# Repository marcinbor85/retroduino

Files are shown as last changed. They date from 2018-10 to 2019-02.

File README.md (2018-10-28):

# retroduino
Open hardware 8051-based arduino-compatible microcomputer

## Features
- Arduino-mega compatible pinout
- AT89S8253 based
- 32kB RAM for data memory
- 32kB RAM for program code
- 32kB EEPROM for non-volatile program code
- build-in bootloader (booting from ROM, copy EEPROM to RAM and run)
- USB PC connection (fast program code loading directly to RAM or to EEPROM)
- external data bus for external peripherals

## PCB
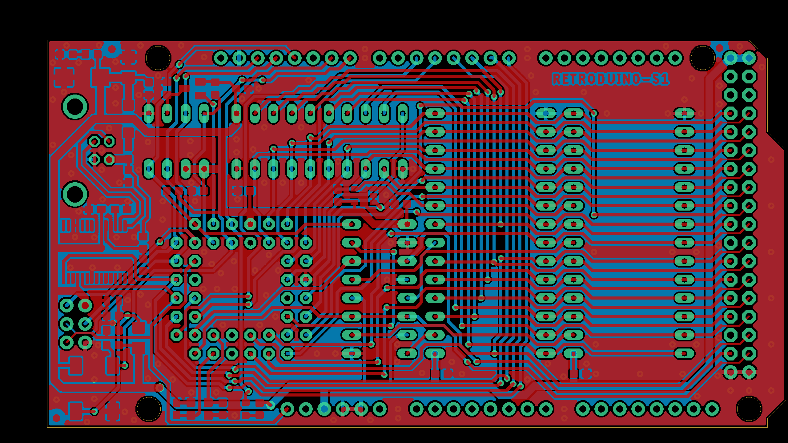
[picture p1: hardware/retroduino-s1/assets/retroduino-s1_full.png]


## Electric diagram
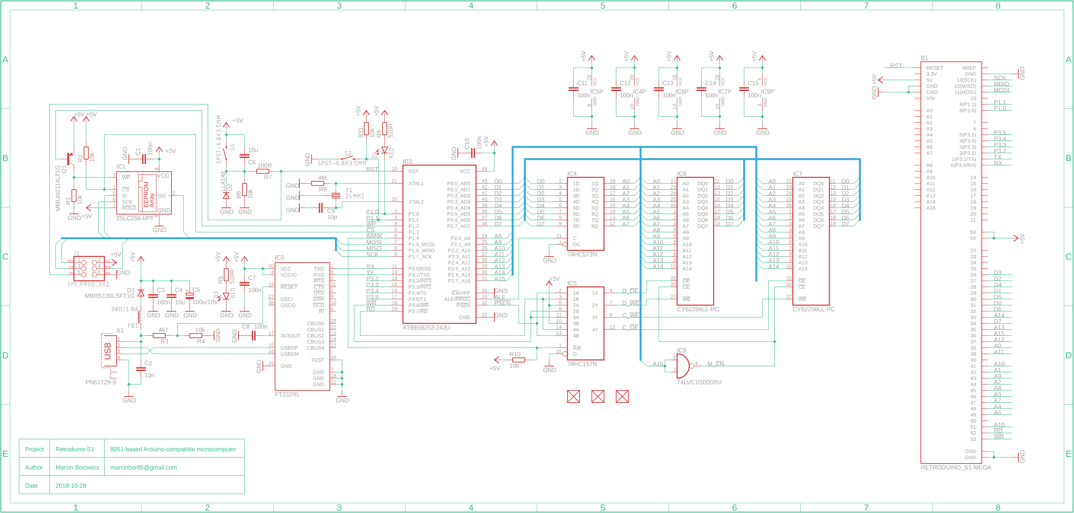
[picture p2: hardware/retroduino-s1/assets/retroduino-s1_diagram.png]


## Project purpose
- "because you can"

## Programming
- recommended SDCC compiler

## Memory layout

### Program bus
- 0x0000-0x2FFF - internal flash with bootloader
- 0x8000-0xFFFF - external program code memory
### Data bus
- 0x0000-0x00FF - internal ram
- 0x0100-0x7FFF - external peripherals
- 0x8000-0xFFFF - external data memory

## TODO
- [ ] external boards with digital and analog input/outputs
- [ ] PC application to loading code to the retroduino board
- [ ] bootloader with code loading, flashing, coping and app running
- [ ] example firmware applications

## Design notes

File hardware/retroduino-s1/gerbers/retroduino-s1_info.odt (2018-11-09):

PCB: retroduino-s1

Wymiary: 101.6 x 53.3 mm

Laminat: FR4 1.5mm dwuwarstwowy/dwustronny

Miedź: 35um

Wykończenie: HAL + Metalizacja

Soldermaska: Zielona

Bez warstwy opisowej

Ilość otworów: 446

Przelotki: 0.4mm

Ścieżka: 0.25mm

Odstępy: 0.25mm

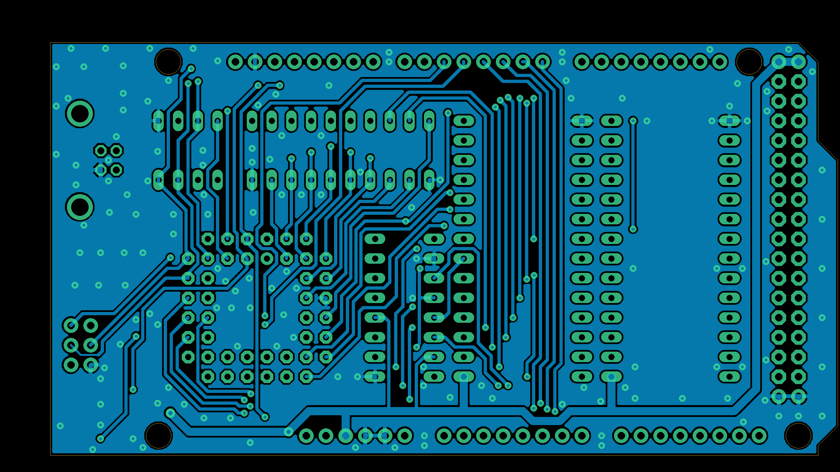
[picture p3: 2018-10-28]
hardware/retroduino-s1/assets/retroduino-s1_bot.png

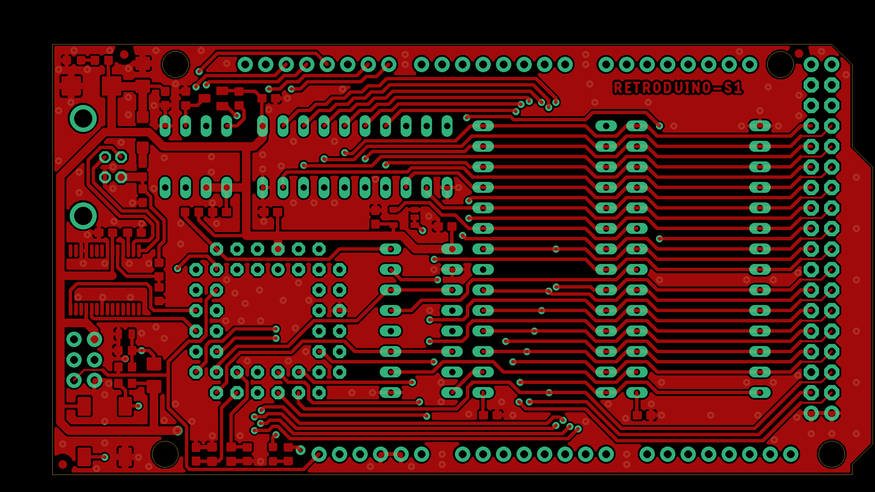
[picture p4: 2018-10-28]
hardware/retroduino-s1/assets/retroduino-s1_top.png

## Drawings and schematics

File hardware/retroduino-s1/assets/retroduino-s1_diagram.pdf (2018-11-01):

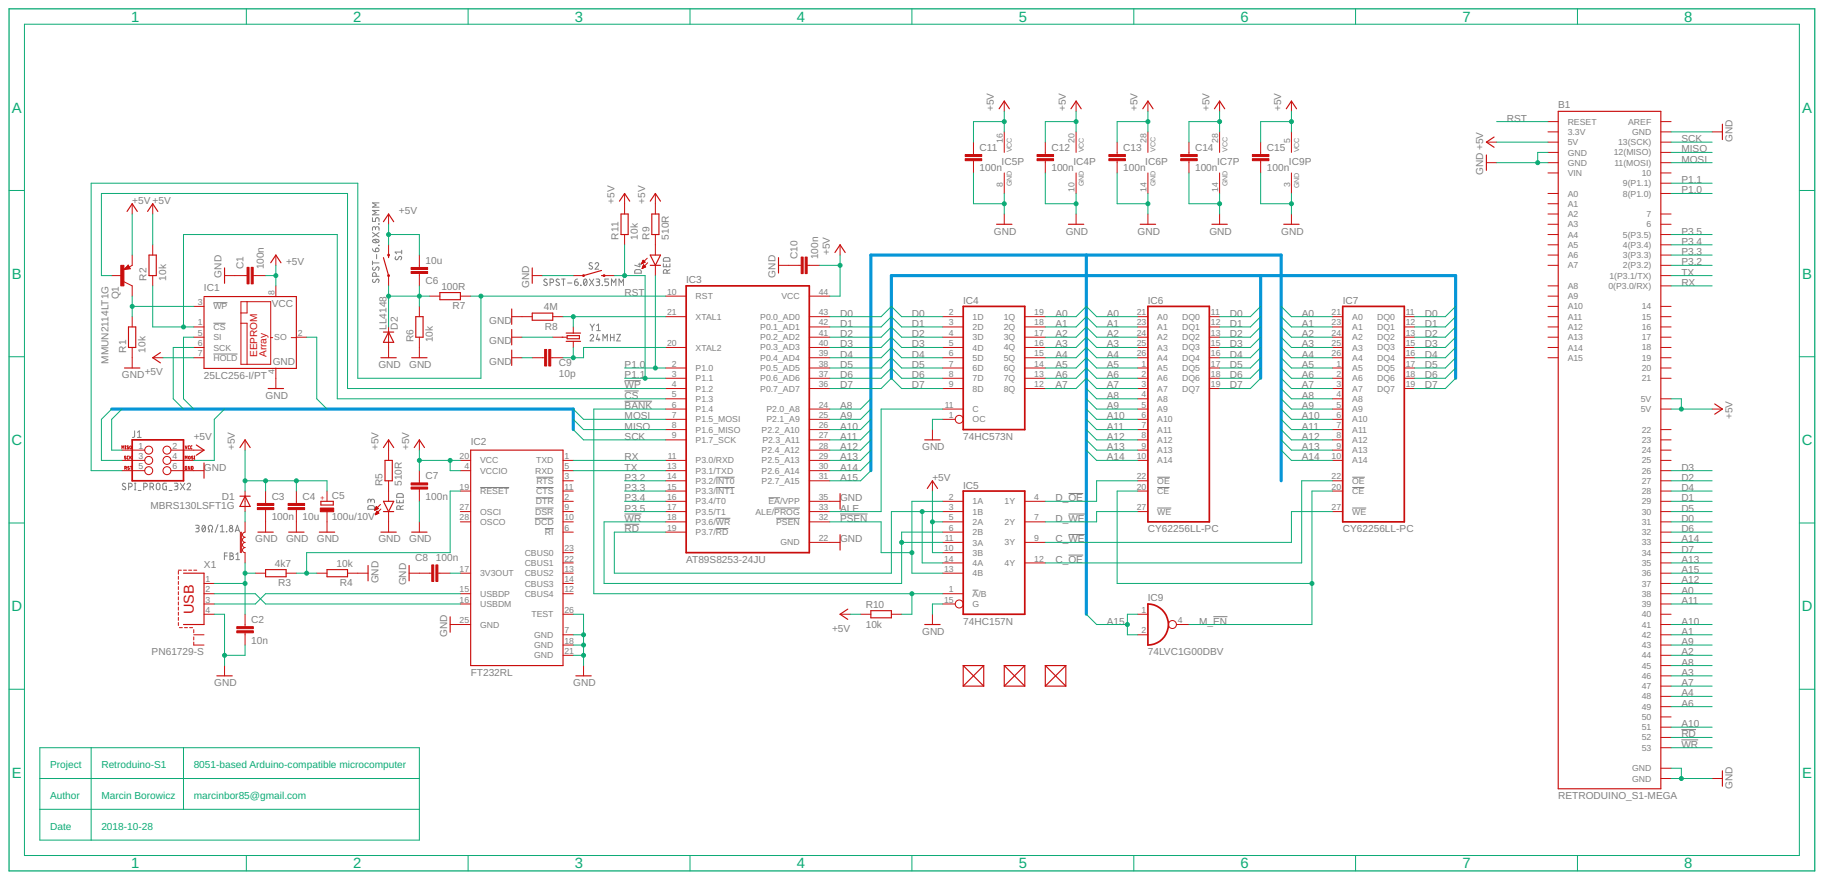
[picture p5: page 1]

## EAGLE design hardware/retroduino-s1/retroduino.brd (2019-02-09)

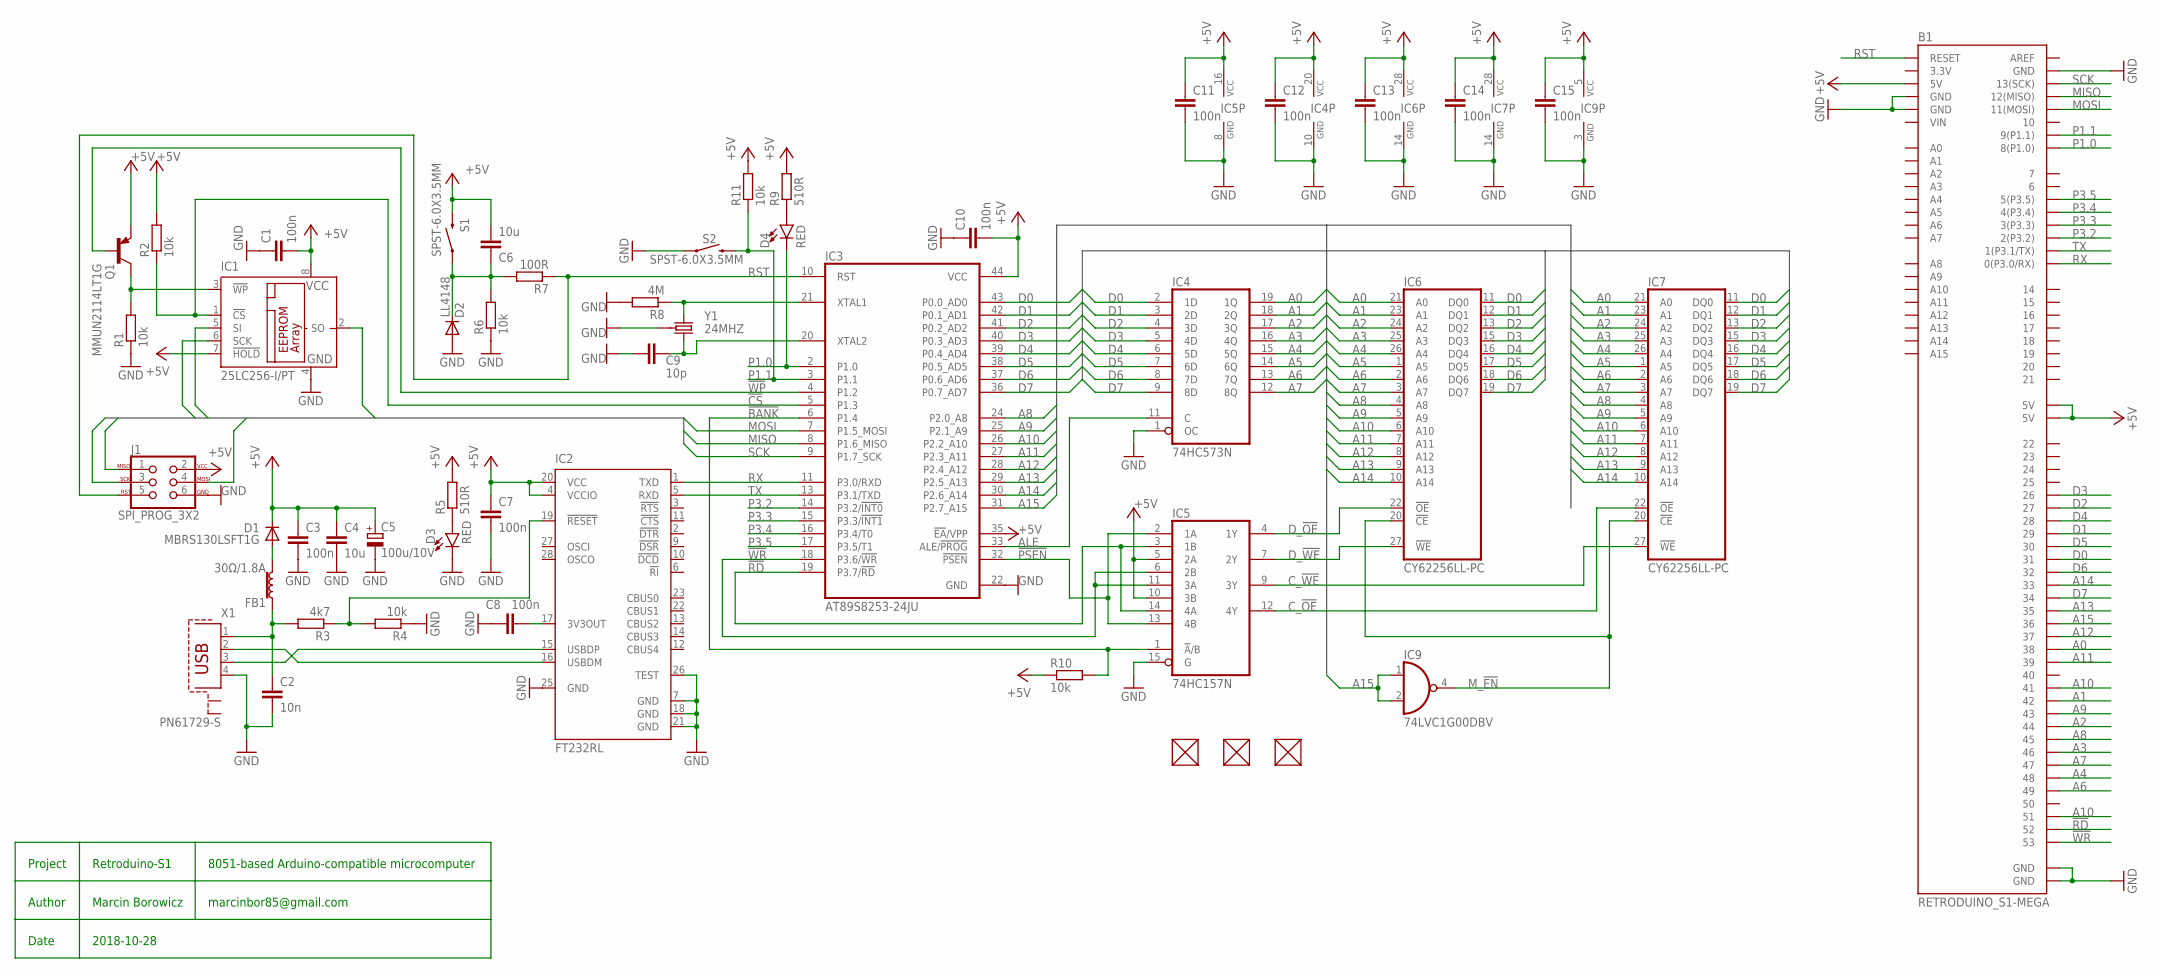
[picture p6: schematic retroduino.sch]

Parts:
B1: RETRODUINO_S1-MEGA; RETRODUINO_S1
C1, C3, C7, C8, C10, C11, C12, C13, C14, C15: 100n; C0603
C2: 10n; C0603
C4, C6: 10u; C1206
C5: 100u/10V; SMC_C
C9: 10p; C0603
D1: MBRS130LSFT1G; SOD123
D2: LL4148; MICROMELF-R
D3, D4: RED; LED-0603
FB1: 30Ω/1.8A; 0603
FUD1, FUD2, FUD3: FIDUCIAL; GHI_FIDUCIAL_40MIL
IC1: 25LC256-I/PT; DIL8
IC2: FT232RL; SSOP28
IC3: AT89S8253-24JU; S44
IC4: 74HC573N; DIL20
IC5: 74HC157N; DIL16
IC6, IC7: CY62256LL-PC; DIL28-6
IC9: 74LVC1G00DBV; SOT23-5
J1: SPI_PROG_3X2; 2X3-NS
Q1: MMUN2114LT1G; SOT23-BEC
R1, R2, R4, R6, R10, R11: 10k; R0603
R3: 4k7; R0603
R5, R9: 510R; R0603
R7: 100R; R0603
R8: 4M; R0603
S1, S2: SPST-6.0X3.5MM; TACTILE_SWITCH_SMD_6.0X3.5MM
X1: PN61729-S
Y1: 24MHZ; CRYSTAL-SMD-3.2X2.5MM

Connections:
!BANK: IC3.6 (P1.4), IC5.1 (!A!/B), R10.2
!CS: IC1.1 (!CS), IC3.5 (P1.3), R2.1
!PSEN: IC3.32 (!PSEN), IC5.2 (1A), IC5.13 (4B)
!RD: B1.52, IC3.19 (P3.7/!RD), IC5.3 (1B), IC5.14 (4A)
!WP: IC3.4 (P1.2), Q1.B
!WR: B1.53, IC3.18 (P3.6/!WR), IC5.6 (2B), IC5.11 (3A)
+5V: B1.5V@0 (5V), B1.5V@1 (5V), B1.5V@2 (5V), C1.2, C3.1, C4.1, C5.+, C6.1, C7.1, C10.2, C11.1, C12.1, C13.1, C14.1, C15.1, D1.C, IC1.7 (!HOLD), IC1.8 (VCC), IC2.4 (VCCIO), IC2.20 (VCC), IC3.35 (!EA!/VPP), IC3.44 (VCC), IC4.20 (VCC), IC5.5 (2A), IC5.10 (3B), IC5.16 (VCC), IC6.28 (VCC), IC7.28 (VCC), IC9.5 (VCC), J1.2, Q1.E, R2.2, R5.2, R9.2, R10.1, R11.2, S1.2
A0: B1.38, IC4.19 (1Q), IC6.21 (A0), IC7.21 (A0)
A1: B1.42, IC4.18 (2Q), IC6.23 (A1), IC7.23 (A1)
A2: B1.44, IC4.17 (3Q), IC6.24 (A2), IC7.24 (A2)
A3: B1.46, IC4.16 (4Q), IC6.25 (A3), IC7.25 (A3)
A4: B1.48, IC4.15 (5Q), IC6.26 (A4), IC7.26 (A4)
A5: IC4.14 (6Q), IC6.1 (A5), IC7.1 (A5)
A6: B1.49, IC4.13 (7Q), IC6.2 (A6), IC7.2 (A6)
A7: B1.47, IC4.12 (8Q), IC6.3 (A7), IC7.3 (A7)
A8: B1.45, IC3.24 (P2.0_A8), IC6.4 (A8), IC7.4 (A8)
A9: B1.43, IC3.25 (P2.1_A9), IC6.5 (A9), IC7.5 (A9)
A10: B1.41, B1.51, IC3.26 (P2.2_A10), IC6.6 (A10), IC7.6 (A10)
A11: B1.39, IC3.27 (P2.3_A11), IC6.7 (A11), IC7.7 (A11)
A12: B1.37, IC3.28 (P2.4_A12), IC6.8 (A12), IC7.8 (A12)
A13: B1.35, IC3.29 (P2.5_A13), IC6.9 (A13), IC7.9 (A13)
A14: B1.33, IC3.30 (P2.6_A14), IC6.10 (A14), IC7.10 (A14)
A15: B1.36, IC3.31 (P2.7_A15), IC9.1 (I0), IC9.2 (I1)
ALE: IC3.33 (ALE/!PROG), IC4.11 (C)
C_!OE: IC5.12 (4Y), IC7.22 (!OE)
C_!WE: IC5.9 (3Y), IC7.27 (!WE)
D0: B1.31, IC3.43 (P0.0_AD0), IC4.2 (1D), IC6.11 (DQ0), IC7.11 (DQ0)
D1: B1.29, IC3.42 (P0.1_AD1), IC4.3 (2D), IC6.12 (DQ1), IC7.12 (DQ1)
D2: B1.27, IC3.41 (P0.2_AD2), IC4.4 (3D), IC6.13 (DQ2), IC7.13 (DQ2)
D3: B1.26, IC3.40 (P0.3_AD3), IC4.5 (4D), IC6.15 (DQ3), IC7.15 (DQ3)
D4: B1.28, IC3.39 (P0.4_AD4), IC4.6 (5D), IC6.16 (DQ4), IC7.16 (DQ4)
D5: B1.30, IC3.38 (P0.5_AD5), IC4.7 (6D), IC6.17 (DQ5), IC7.17 (DQ5)
D6: B1.32, IC3.37 (P0.6_AD6), IC4.8 (7D), IC6.18 (DQ6), IC7.18 (DQ6)
D7: B1.34, IC3.36 (P0.7_AD7), IC4.9 (8D), IC6.19 (DQ7), IC7.19 (DQ7)
D_!OE: IC5.4 (1Y), IC6.22 (!OE)
D_!WE: IC5.7 (2Y), IC6.27 (!WE)
GND: B1.GND@0 (GND), B1.GND@1 (GND), B1.GND@2 (GND), B1.GND@3 (GND), B1.GND@4 (GND), C1.1, C2.2, C3.2, C4.2, C5.-, C7.2, C8.2, C9.1, C10.1, C11.2, C12.2, C13.2, C14.2, C15.2, D2.A, D3.C, IC1.4 (GND), IC2.7 (GND), IC2.18 (GND), IC2.21 (GND), IC2.25 (GND), IC2.26 (TEST), IC3.22 (GND), IC4.1 (OC), IC4.10 (GND), IC5.8 (GND), IC5.15 (G), IC6.14 (GND), IC7.14 (GND), IC9.3 (GND), J1.6, R1.1, R4.1, R6.1, R8.2, S2.1, X1.4, Y1.2 (3), Y1.4 (3)
MISO: B1.12 (12(MISO)), IC1.2 (SO), IC3.8 (P1.6_MISO), J1.1
MOSI: B1.11 (11(MOSI)), IC1.5 (SI), IC3.7 (P1.5_MOSI), J1.4
M_!EN: IC6.20 (!CE), IC7.20 (!CE), IC9.4 (O)
unnamed: C9.2, IC3.20 (XTAL2), Y1.3 (2)
unnamed: IC3.21 (XTAL1), R8.1, Y1.1
unnamed: C6.2, D2.C, R6.2, R7.2, S1.1
unnamed: D3.A, R5.1
unnamed: D4.A, R9.1
unnamed: IC2.16 (USBDM), X1.2
unnamed: C8.1, IC2.17 (3V3OUT)
unnamed: IC2.15 (USBDP), X1.3
unnamed: C2.1, FB1.1, R3.2, X1.1
unnamed: IC1.3 (!WP), Q1.C, R1.2
unnamed: D1.A, FB1.2
unnamed: IC2.19 (!RESET), R3.1, R4.2
P1.0: B1.8 (8(P1.0)), D4.C, IC3.2 (P1.0)
P1.1: B1.9 (9(P1.1)), IC3.3 (P1.1), R11.1, S2.2
P3.2: B1.2 (2(P3.2)), IC3.14 (P3.2/!INT0)
P3.3: B1.3 (3(P3.3)), IC3.15 (P3.3/!INT1)
P3.4: B1.4 (4(P3.4)), IC3.16 (P3.4/T0)
P3.5: B1.5 (5(P3.5)), IC3.17 (P3.5/T1)
RST: B1.RESET, IC3.10 (RST), J1.5, R7.1
RX: B1.0 (0(P3.0/RX)), IC2.1 (TXD), IC3.11 (P3.0/RXD)
SCK: B1.13 (13(SCK)), IC1.6 (SCK), IC3.9 (P1.7_SCK), J1.3
TX: B1.1 (1(P3.1/TX)), IC2.5 (RXD), IC3.13 (P3.1/TXD)

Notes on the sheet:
Author
Project
Date
Marcin Borowicz
Retroduino-S1
2018-10-28
8051-based Arduino-compatible microcomputer
marcinbor85@gmail.com

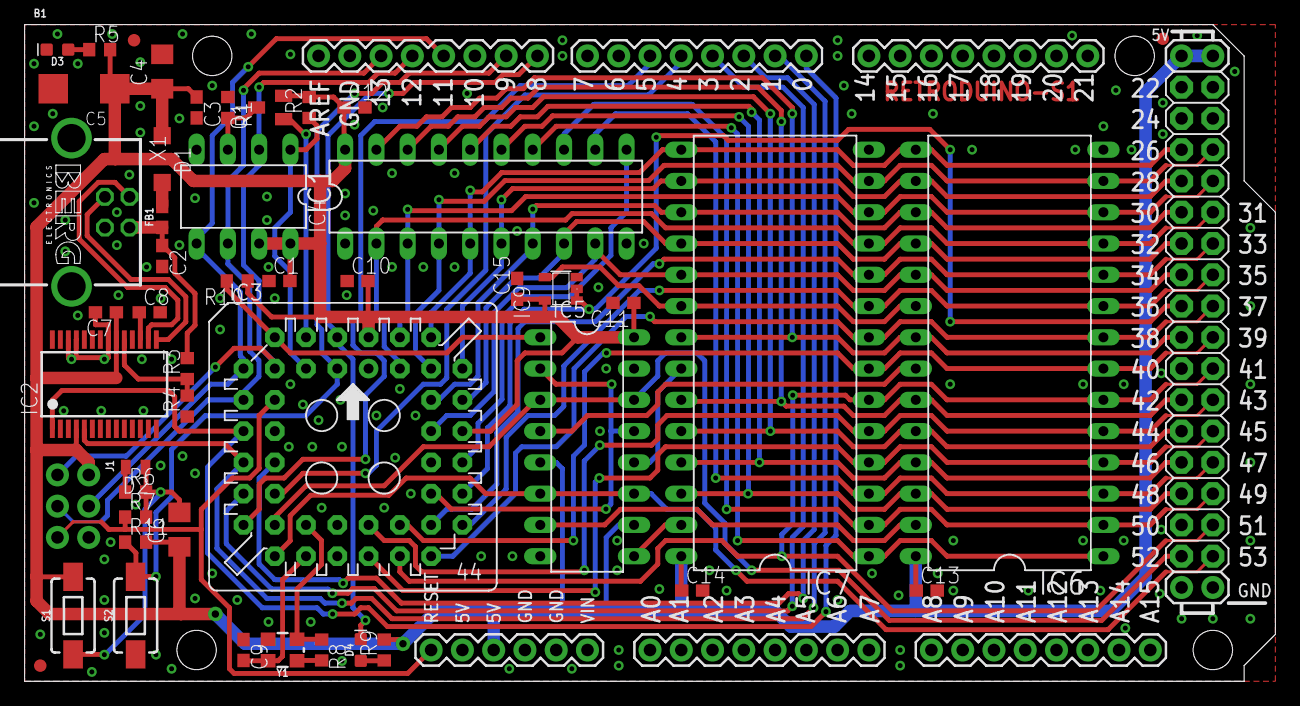
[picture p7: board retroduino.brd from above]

Board: 2 copper layers, 101.6 x 53.3 mm, 49 parts (0 on the bottom side), 62 nets.

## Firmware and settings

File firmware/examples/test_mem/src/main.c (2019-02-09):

#include <at89s8253.h>
#include <stdint.h>

#define LED_PIN_STATE           P1_0
#define BUTTON_PIN_STATE        P1_1
#define BANK_PIN_SELECT         P1_4

#define EXTMEM_ADR_START        ((uint16_t)0x8000)
#define EXTMEM_ADR_END          ((uint16_t)0xFFFF)

static void delay(uint16_t val)
{
        while (val-- > 0) {};
}

static void blinking_loop(void)
{
        uint8_t i = 0;
 
        LED_PIN_STATE = i;
        while (1) {
                delay(50000);
                i = (i == 0) ? 1 : 0;
                LED_PIN_STATE = i;
        }
}

static void signal_error(void)
{
        LED_PIN_STATE = 0;
        while (1) {};
}

static uint8_t calc_pattern(uint16_t adr, uint8_t b)
{
        b ^= adr >> 8;
        b ^= adr;
        return b;
}

static void fill_memory(uint16_t adr_start, uint16_t adr_end, uint8_t pattern)
{
        uint16_t adr;
        uint8_t b;

        adr = adr_start;
        while ((adr >= adr_start) && (adr <= adr_end)) {
                b = calc_pattern(adr, pattern++);
                *(__xdata uint8_t*)adr++ = b;                
        }
}

static uint8_t check_memory(uint16_t adr_start, uint16_t adr_end, uint8_t pattern)
{
        uint16_t adr;
        uint8_t b;

        adr = adr_start;
        while ((adr >= adr_start) && (adr <= adr_end)) {
                b = calc_pattern(adr, pattern++);
                if (*(__xdata uint8_t*)adr++ != b)
                        return 1;
        }

        return 0;
}

static void uart_send_byte(uint8_t ch)
{
        SBUF = ch;
        while (TI == 0) {};
        TI = 0;
}

static uint8_t uart_recv_byte(void)
{
        uint8_t ch;

        while (RI == 0) {};
        ch = SBUF;
        RI = 0;
        return ch;
}

static void uart_init(uint32_t baudrate)
{ 
        SCON = 0x50;
        TMOD = 0x20;
        TH1 = 256 - (24000000UL) / (uint32_t)(32UL * 6UL * baudrate);
        TR1 = 1;
}

static void uart_send_data(uint8_t *data, uint16_t size)
{
        while (size-- > 0) {
                uart_send_byte(*data++);
        }
}

static void uart_send_string(char *data)
{
        while (*data != 0) {
                uart_send_byte(*data++);
        }
}

static void echo_loop(void)
{
        uint8_t b;

        while (1) {
                b = uart_recv_byte();
                uart_send_byte(b);
        }
}

void main(void)
{
        LED_PIN_STATE = 1;

        uart_init(9600);

        while (1) {
                BANK_PIN_SELECT = 1;
                fill_memory(EXTMEM_ADR_START, EXTMEM_ADR_END, 0x55);
                if (check_memory(EXTMEM_ADR_START, EXTMEM_ADR_END, 0x55) != 0)
                        break;

                BANK_PIN_SELECT = 0;
                fill_memory(EXTMEM_ADR_START, EXTMEM_ADR_END, 0xAA);
                if (check_memory(EXTMEM_ADR_START, EXTMEM_ADR_END, 0xAA) != 0)
                        break;

                BANK_PIN_SELECT = BUTTON_PIN_STATE;
                if (check_memory(EXTMEM_ADR_START, EXTMEM_ADR_END, 0x55) != 0)
                        break;

                uart_send_string("OK");
                blinking_loop();
        }

        LED_PIN_STATE = 0;
        uart_send_string("ERROR");
        echo_loop();
}

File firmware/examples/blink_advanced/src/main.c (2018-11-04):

#include "app/logic.h"

#include "bsp/bsp.h"

#include "sys/tick.h"

#include "types.h"

void external0_isr(void) __interrupt(0)
{

}

void timer0_isr(void) __interrupt(1)
{
        tick_increment();
}

void external1_isr(void) __interrupt(2)
{

}

void timer1_isr(void) __interrupt(3)
{

}

void serialport_isr(void) __interrupt(4)
{

}

void main(void)
{
        tick_init();
        bsp_init();
        logic_init();

        while (1) {
                bsp_service();
                logic_service();
        }
}

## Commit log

2018-10-28 pcb project added
    [retroduino.brd, retroduino.sch]
2018-10-28 diagram and assets updated
    [retroduino.sch]
2018-11-01 dodany email na schemacie
    [retroduino.sch]
2018-11-04 dodany przykład z prostym led blinkiem
2018-11-04 dodany przykład z zaawansowanym led blinkiem
2018-11-09 dodane gerbery
    [copper_bottom.gbr, copper_top.gbr, drills.xln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]
2019-02-09 unsigned int bug fix
    [main.c]
2019-02-09 some pcb bugs fixed:
    1. !ea should be connected to vcc due to allow boot from internal flash
    2. missing microcontroller gnd supply (pin 22)
    [retroduino.brd, retroduino.sch]

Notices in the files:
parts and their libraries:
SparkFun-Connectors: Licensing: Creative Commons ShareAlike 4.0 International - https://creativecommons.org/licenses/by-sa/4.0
